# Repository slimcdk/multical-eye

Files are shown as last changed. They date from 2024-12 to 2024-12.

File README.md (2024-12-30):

# IR Eye for Kamstrup MultiCal

## Production files



## Contribution

Clone repository and fetch submodules

```bash
$ git clone --recursive-submodules git@github.com:slimcdk/multical-eye.git
```

## Versioning

Revisions are controlled through git tags such any production easily can be traced back to a commit containing everything. Complete sets of compatible schematics, PCB layouts, documentations, 3D models etc will all stay together under same tag in the source history.

---

## Software uses

* https://www.kicad.org/
* https://www.freecadweb.org/
* https://github.com/features/actions
  * https://github.com/INTI-CMNB/KiBot
* https://code.visualstudio.com/
  * https://marketplace.visualstudio.com/items?itemName=ms-vscode-remote.remote-containers

## Notes

### Parts

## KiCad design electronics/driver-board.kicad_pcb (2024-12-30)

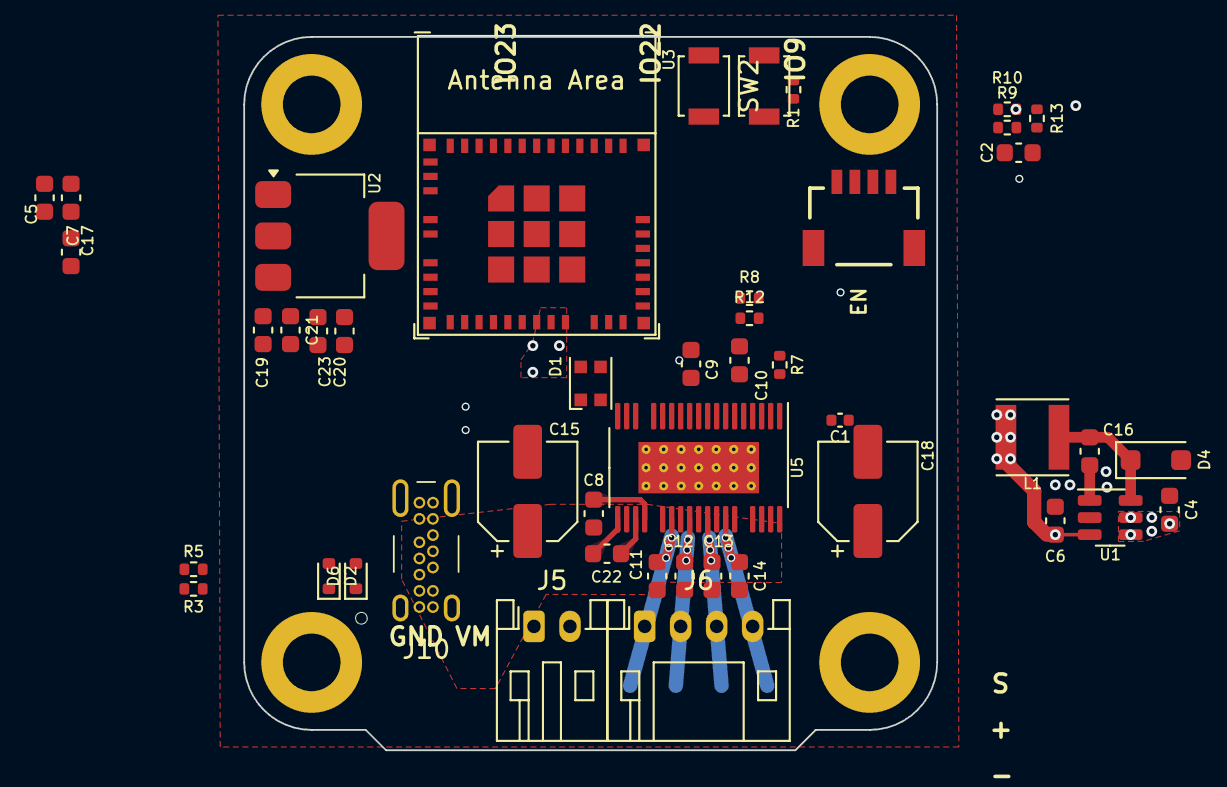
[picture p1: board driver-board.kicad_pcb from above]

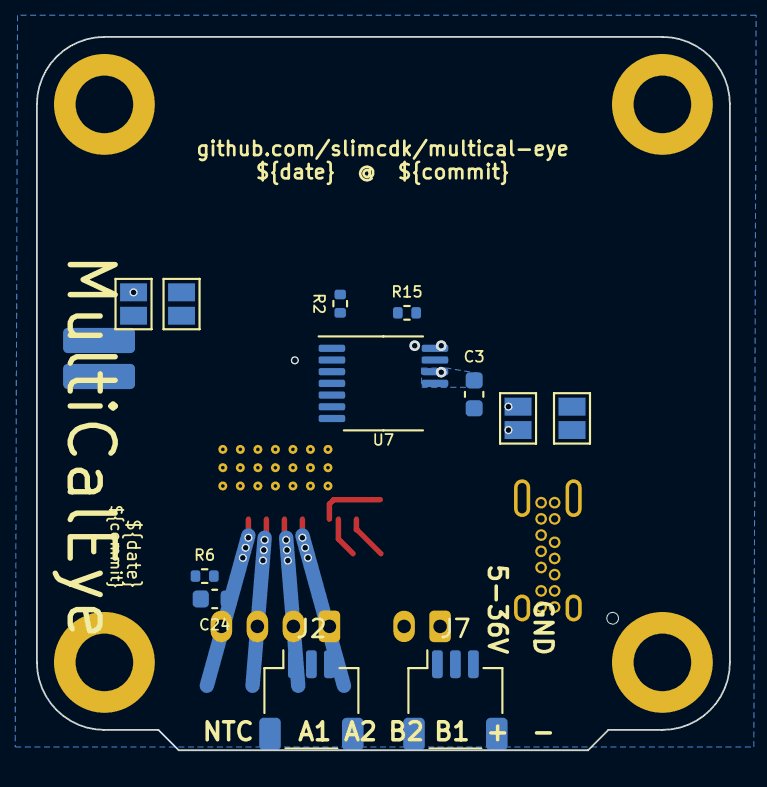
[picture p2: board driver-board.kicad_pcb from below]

Board: 4 copper layers, 38.5 x 39.6 mm, 63 parts (13 on the bottom side), 42 nets.

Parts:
C1: 100nF; C_0402_1005Metric
C2, C7, C8, C13, C14: 1µF; C_0603_1608Metric
C3, C9, C11, C12, C16, C17, C19, C23, C24: 100nF; C_0603_1608Metric
C4, C10: 2.2µF; C_0603_1608Metric
C5, C6, C20, C21: 10µF; C_0603_1608Metric
C15, C18: 33µF; CP_Elec_5x5.9
C22: 22nF; C_0603_1608Metric
D1: WS2812B; LED_WS2812B-2020_PLCC4_2.0x2.0mm
D2, D6: LESD5D5; D_SOD-523
D4: DS210W; D_SOD-123F
H1, H2, H3, H4: M3 MountingHole; MountingHole_3.2mm_M3_DIN965_Pad
J1: Conn_01x02; PinHeader_1x02_P2.00mm_Vertical_SMD_Pin1Left
J2, J7: Conn_01x03; JST_SH_SM03B-SRSS-TB_1x03-1MP_P1.00mm_Horizontal
J4: Qwiic_RA; JST_SMD_1.0mm-4_RA
J5: Conn_01x02; JST_PH_S2B-PH-K_1x02_P2.00mm_Horizontal
J6: Conn_01x04; JST_PH_S4B-PH-K_1x04_P2.00mm_Horizontal
J10: USB_C_Receptacle_USB2.0; USB_C_GT-USB-7036A
JP1, JP2, JP3, JP4: Jumper_2_Open; SolderJumper-2_P1.3mm_Open_Pad1.0x1.5mm
L1: 6.8µH; L_Vishay_IFSC-1515AH_4x4x1.8mm
R1, R2, R6, R8, R9, R10, R12, R13, R15: 10k; R_0402_1005Metric
R3, R5: 5k1; R_0402_1005Metric
R7: 12k; R_0402_1005Metric
SW1, SW2: SW_Push; SW_SPST_B3U-1000P
U1: LMR16006YQ3; SOT-23-6
U2: AMS1117-3.3; SOT-223-3_TabPin2
U3: ESP32-C6-MINI-1/U; ESP32-C6-MINI-1
U5: TMC5240-TSSOP38; TSSOP-38_4.4x9.7mm_P0.5mm
U7: AS5047D; TSSOP-14_4.4x5mm_P0.65mm

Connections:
+3V3: C1.1, C3.2, C5.2, C6.2, C7.2, C9.2, C17.2, C20.2, C23.1, D1.1 (VDD), J2.2, J4.2, J7.2, L1.2, R1.2, R2.2, R6.2, R8.2, R9.2, R10.2, R12.2, R13.2, U1.3 (FB), U2.2 (VO), U3.3 (3V3), U5.11 (VCC_IO), U7.11 (VDD), U7.12 (VDD3V3)
+5V: C19.1, C21.2, J10.A4 (VBUS), J10.A9 (VBUS), J10.B4 (VBUS), J10.B9 (VBUS), U2.3 (VI)
/AS_ENCA: JP1.1 (A), U5.14 (ENCA), U7.7 (A)
/AS_ENCB: JP2.1 (A), U5.13 (ENCB), U7.6 (B)
/AS_ENCN: U5.12 (ENCN), U7.14 (I/PWM)
/ESP_BOOT: R1.1, SW2.2, U3.23 (GPIO9)
/ESP_EN: C2.1, R13.1, SW1.1, U3.8 (EN/CHIP_PU)
/ESP_GPIO0: R15.1, U3.12 (GPIO0/ADC1_CH0/XTAL_32K_P), U5.15 (DRV_EN)
/ESP_GPIO1: JP1.2 (B), U3.13 (GPIO1/ADC1_CH1/XTAL_32K_N)
/ESP_GPIO2: D1.4 (DIN), U3.5 (GPIO2/ADC1_CH2)
/ESP_GPIO3: JP2.2 (B), U3.6 (GPIO3/ADC1_CH3)
/ESP_GPIO4: U3.9 (MTMS/GPIO4/ADC1_CH4), U5.18 (DIAG1/SW)
/ESP_GPIO5: U3.10 (MTDI/GPIO5/ADC1_CH5), U5.17 (DIAG0)
/ESP_GPIO6: U3.15 (MTCK/GPIO6/ADC1_CH6), U5.2 (SDO/NAO), U7.3 (MISO)
/ESP_GPIO7: R2.1, U3.16 (MTDO/GPIO7), U7.1 (~CS)
/ESP_GPIO8: U3.22 (GPIO8), U5.38 (SCK/AD1), U7.2 (CLK)
/ESP_GPIO12: D2.2 (A2), J10.A7 (D-), J10.B7 (D-), U3.17 (GPIO12/USB_D-)
/ESP_GPIO13: D6.2 (A2), J10.A6 (D+), J10.B6 (D+), U3.18 (GPIO13/USB_D+)
/ESP_GPIO14: U3.19 (GPIO14), U5.1 (SDI/AD0), U7.4 (MOSI)
/ESP_GPIO15: U3.20 (GPIO15), U5.36 (CS/AD2)
/ESP_GPIO16: J4.4, R10.1, U3.31 (U0TXD/GPIO16)
/ESP_GPIO17: J4.3, R9.1, U3.30 (U0RXD/GPIO17)
/ESP_GPIO20: JP4.2 (B), U3.26 (GPIO20)
/ESP_GPIO21: JP3.1 (A), U3.27 (GPIO21)
/TMC_AIN: C24.2, J1.2, R6.1, U5.8 (AIN)
/TMC_OUT1A: J6.4, U5.32 (OUT1A)
/TMC_OUT1B: J6.2, U5.26 (OUT1B)
/TMC_OUT2A: J6.3, U5.30 (OUT2A)
/TMC_OUT2B: J6.1, U5.28 (OUT2B)
/TMC_REFL: J2.3, JP3.2 (B), R8.1, U5.5 (REFL)
/TMC_REFR: J7.3, JP4.1 (A), R12.1, U5.6 (REFR)
/USB_CC1: J10.A5 (CC1), R5.1
/USB_CC2: J10.B5 (CC2), R3.1
GND: C1.2, C2.2, C3.1, C4.1, C5.1, C6.1, C7.1, C9.1, C10.1, C11.2, C12.2, C13.2, C14.2, C15.2, C17.1, C18.2, C19.2, C20.1, C21.1, C23.2, C24.1, D1.3 (VSS), D2.1 (A1), D4.2 (A), D6.1 (A1), J1.1, J2.1, J4.1, J5.1, J7.1, J10.A1 (GND), J10.A12 (GND), J10.B1 (GND), J10.B12 (GND), R3.2, R5.2, R7.2, R15.2, SW1.2, SW2.1, U1.2 (GND), U2.1 (GND), U3.1 (GND), U3.2 (GND), U3.11 (GND), U3.14 (GND), U3.36 (GND), U3.37 (GND), U3.38 (GND), U3.39 (GND), U3.40 (GND), U3.41 (GND), U3.42 (GND), U3.43 (GND), U3.44 (GND), U3.45 (GND), U3.46 (GND), U3.47 (GND), U3.48 (GND), U3.49 (GND), U3.50 (GND), U3.51 (GND), U3.52 (GND), U3.53 (GND), U5.3 (CLK), U5.10 (AGND), U5.27 (PGND1), U5.31 (PGND2), U5.39 (EP), U7.5 (TST), U7.13 (GND)
unnamed: C16.1, D4.1 (K), L1.1, U1.6 (SW)
unnamed: C16.2, U1.1 (CB)
unnamed: C22.2, U5.20 (CPI)
unnamed: C22.1, U5.22 (CPO)
unnamed: R7.1, U5.7 (IREF)
unnamed: C8.2, U5.23 (VCP)
unnamed: C10.2, U5.9 (VDD1V8)
VM: C4.2, C8.1, C11.1, C12.1, C13.1, C14.1, C15.1, C18.1, J5.2, U1.4 (~SHDN), U1.5 (VIN), U5.25 (VS1), U5.29 (VS2), U5.33 (VS3), U5.35 (SLEEP)

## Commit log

2024-12-30 init project
    [driver-board.kicad_pcb, driver-board.kicad_sch]
2024-12-30 added slimc kicad libraries
